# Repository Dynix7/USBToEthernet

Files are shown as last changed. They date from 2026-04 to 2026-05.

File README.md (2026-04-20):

# USBToEthernet
This is a design for USB to Ethernet Adapter that (obviously) allows you to use ethernet through a USB port.

# Why I Made It
I made this PCB because I was getting into setting up some sort of homeserver using my old laptop. However, my laptop doesn't have an ethernet port and while I could use WIFI, it wouldn't be optimal for network speed.

# Picture
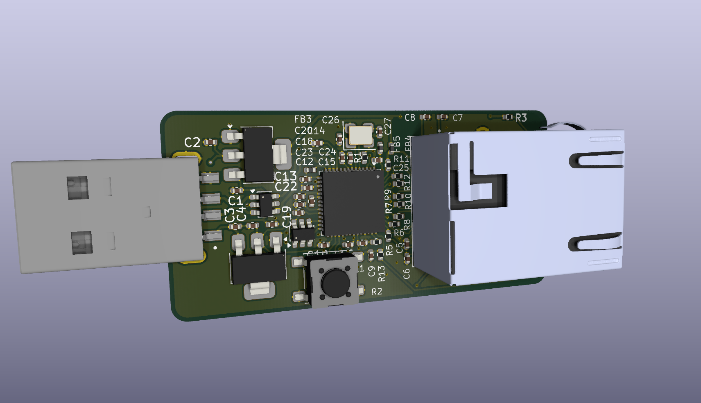
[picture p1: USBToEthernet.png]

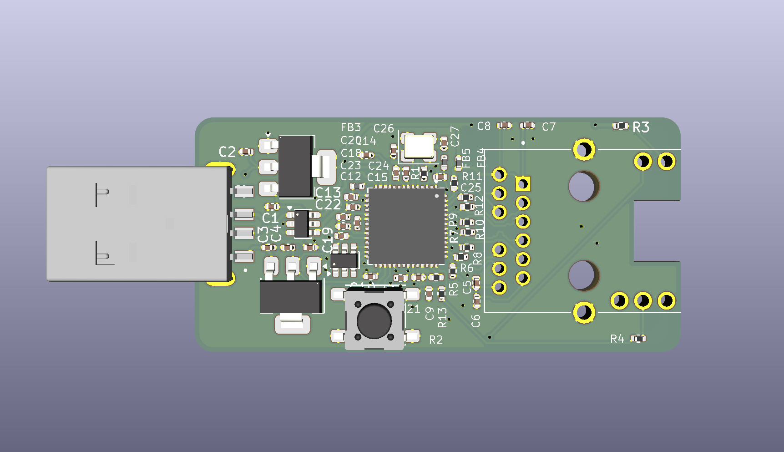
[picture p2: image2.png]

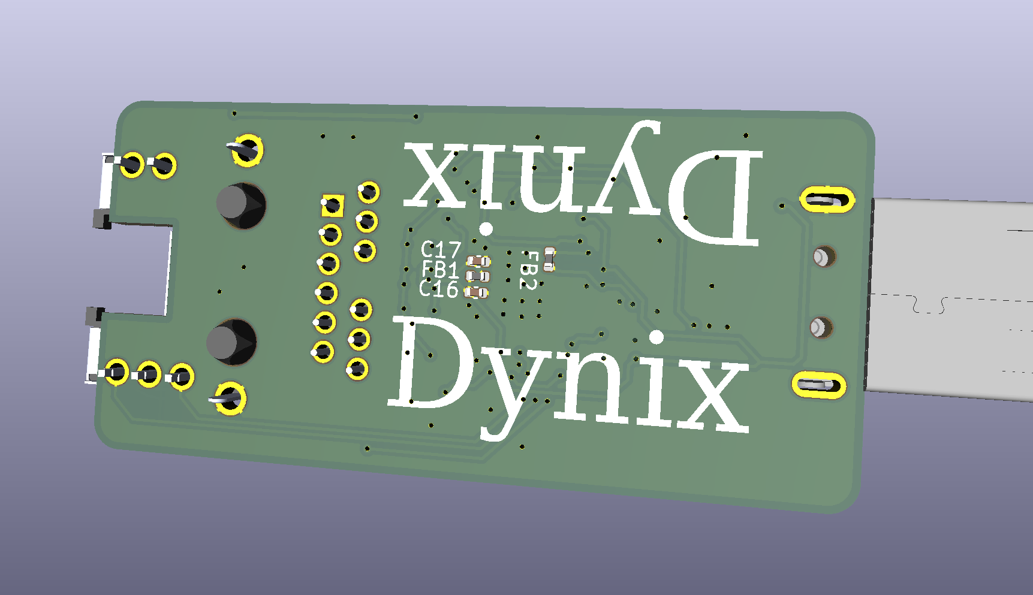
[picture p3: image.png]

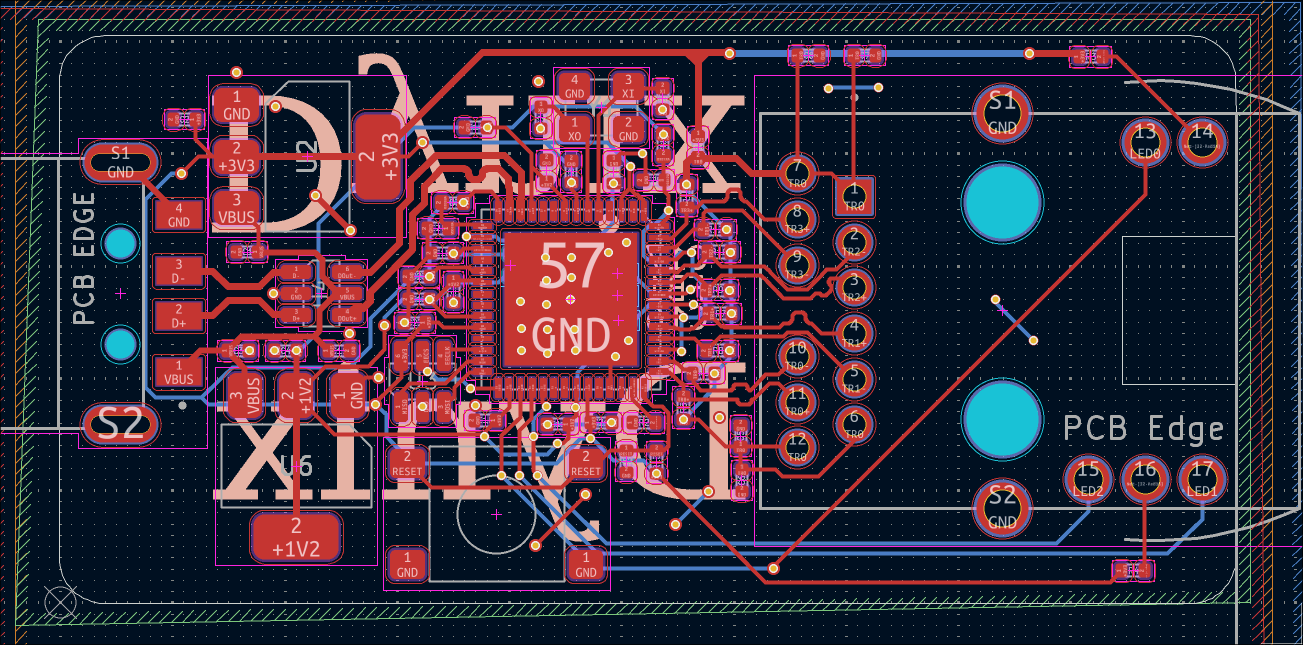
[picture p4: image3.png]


# BOM

|Name |Purpose |Quantity|Total Cost (USD)|Link |Distributor|
|---|---|---|---|---|---|
|10k Resistor |Resistor | |0.06 |https://www.lcsc.com/product-detail/C2906861.html|LCSC |
|8.06k Resistor |Resistor | |0.01 |https://www.lcsc.com/product-detail/C2960789.html|LCSC |
|12k Resistor |Resistor | |0.06 |https://www.lcsc.com/product-detail/C2909316.html|LCSC |
|1k Resistor |Resistor | |0.06 |https://www.lcsc.com/product-detail/C2906864.html|LCSC |
|49.9 Capcitor |Capacitor | |0.06 |https://www.lcsc.com/product-detail/C2933103.html|LCSC |
|24pF Capacitor |Capacitor | |0.12 |https://www.lcsc.com/product-detail/C281755.html |LCSC |
|100nF Capacitor |Decoupling Capacitor | |0.10 |https://www.lcsc.com/product-detail/C60474.html  |LCSC |
|10uF Capacitor |Capacitor | |0.18 |https://www.lcsc.com/product-detail/C14445.html  |LCSC |
|1uF Capacitor |Capacitor | |0.23 |https://www.lcsc.com/product-detail/C14445.html  |LCSC |
|22nF Capacitor |Capacitor | |0.20 |https://www.lcsc.com/product-detail/C1532.html |LCSC |
|120 Ohm Ferrite Bead |Power Filtering |5 |0.90 |https://www.digikey.com/short/c9nm3n45 |Digikey |
|USBLC6-2SC6 |Power Protection |1 |0.36 |https://www.digikey.com/short/m59b7dzr |Digikey |
|NCP1117 Voltage Regulator |Voltage Regulator |1 |0.38 |https://www.digikey.com/short/pvbpmpzr |Digikey |
|USB Plug |For Plugging Into Computer |1 |1.35 |https://www.digikey.com/short/75mfb4tp |Digikey |
|PTS645S Push Button |Reset Button |1 |0.36 |https://www.digikey.com/short/q00wnt84 |Digikey |
|L836-1J1T-43 Ehternet Jack|Ethernet Jack |1 |6.53 |https://www.digikey.com/short/7bz57dt5 |Digikey |
|AMS117 1.2V |Voltage Regulator for LAN7500 |1 |0.10 |https://www.digikey.com/short/jqn99nv8 |Digikey |
|93LC56AT-I/OT |Storage |1 |0.32 |https://www.digikey.com/short/z01d9wp0 |Digikey |
|TSX-3225 25Mhz Crystal |Crystal Oscillator for LAN7500|1 |0.38 |https://www.digikey.com/short/hw0jtcmv |Digikey |
|LAN7500-ABZJ |USB to Ethernet Chip |1 |7.00 |https://www.digikey.com/short/8pjfdmbz |Digikey |
|Stencil |Stencil for Manually Assembly |1 |7.11 | |JLCPCB |
|PCB |PCB for Build |5 |5.20 | |JLCPCB |

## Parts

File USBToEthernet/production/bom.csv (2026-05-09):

Designator | Footprint | Quantity | Value | LCSC Part #
C1, C12, C15_2, C15, C17, C18, C2, C20, C21, C3, C4, C5, C8 | 0402 | 13 | 1uF
C10, C11, C14, C16 | 0402 | 4 | 10uF
C13, C6 | 0402 | 2 | 100nF
C19, C22, C23, C24 | 0402 | 4 | 0.022uF
C7, C9 | 0402 | 2 | 24pF
FB1, FB2, FB3, FB4, FB5 | 0402 | 5 | 120@100
J1 | MOLEX_0480372200 | 1 | 0480372200
J2 | BEL_L836-1J1T-43 | 1 | L836-1J1T-43
R1 | 0402 | 1 | 12k
R10, R11 | 0402 | 2 | 1k
R12, R13, R4, R5, R6, R7, R8, R9 | 0402 | 8 | 49.9
R2 | 0402 | 1 | 8.06k
R3 | 0402 | 1 | 10k
SW1 | SW_SPST_PTS645Sx43SMTR92 | 1 | SW_Push
U1 | SOT-23-6 | 1 | 93LCxxAxxOT
U2 | QFN-56-1EP_8x8mm_P0.5mm_EP5.9x5.9mm | 1 | LAN7500-ABJZ
U3 | SOT-23-6 | 1 | USBLC6-2SC6
U4 | SOT-223-3_TabPin2 | 1 | NCP1117-3.3_SOT223
U5 | SOT-223-3_TabPin2 | 1 | AMS1117-1.2
Y1 | Crystal_SMD_SeikoEpson_FA238V-4Pin_3.2x2.5mm | 1 | 25Mhz

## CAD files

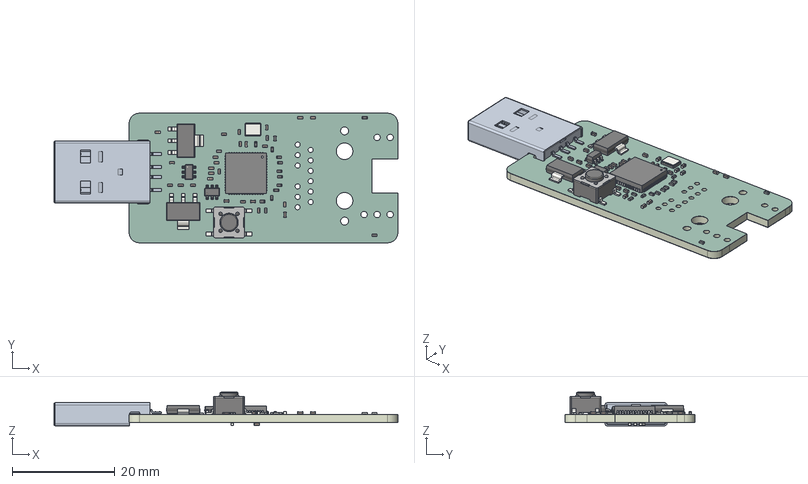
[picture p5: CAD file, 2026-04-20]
pcb.step
67.1 x 25.3 x 6.55 mm
L_0402_1005Metric x 5
R_0402_1005Metric x 13
SOT-23-6 x 2
C_0402_1005Metric x 27
SOT-223 x 2
QFN56_8X8MC_MCH
SW_SPST_PTS645Sx43SMTR92
Crystal_SMD_SeikoEpson_FA238V-4Pin_3.2x2.5mm
USBToEthernet_soldermask x 2
USBToEthernet_PCB

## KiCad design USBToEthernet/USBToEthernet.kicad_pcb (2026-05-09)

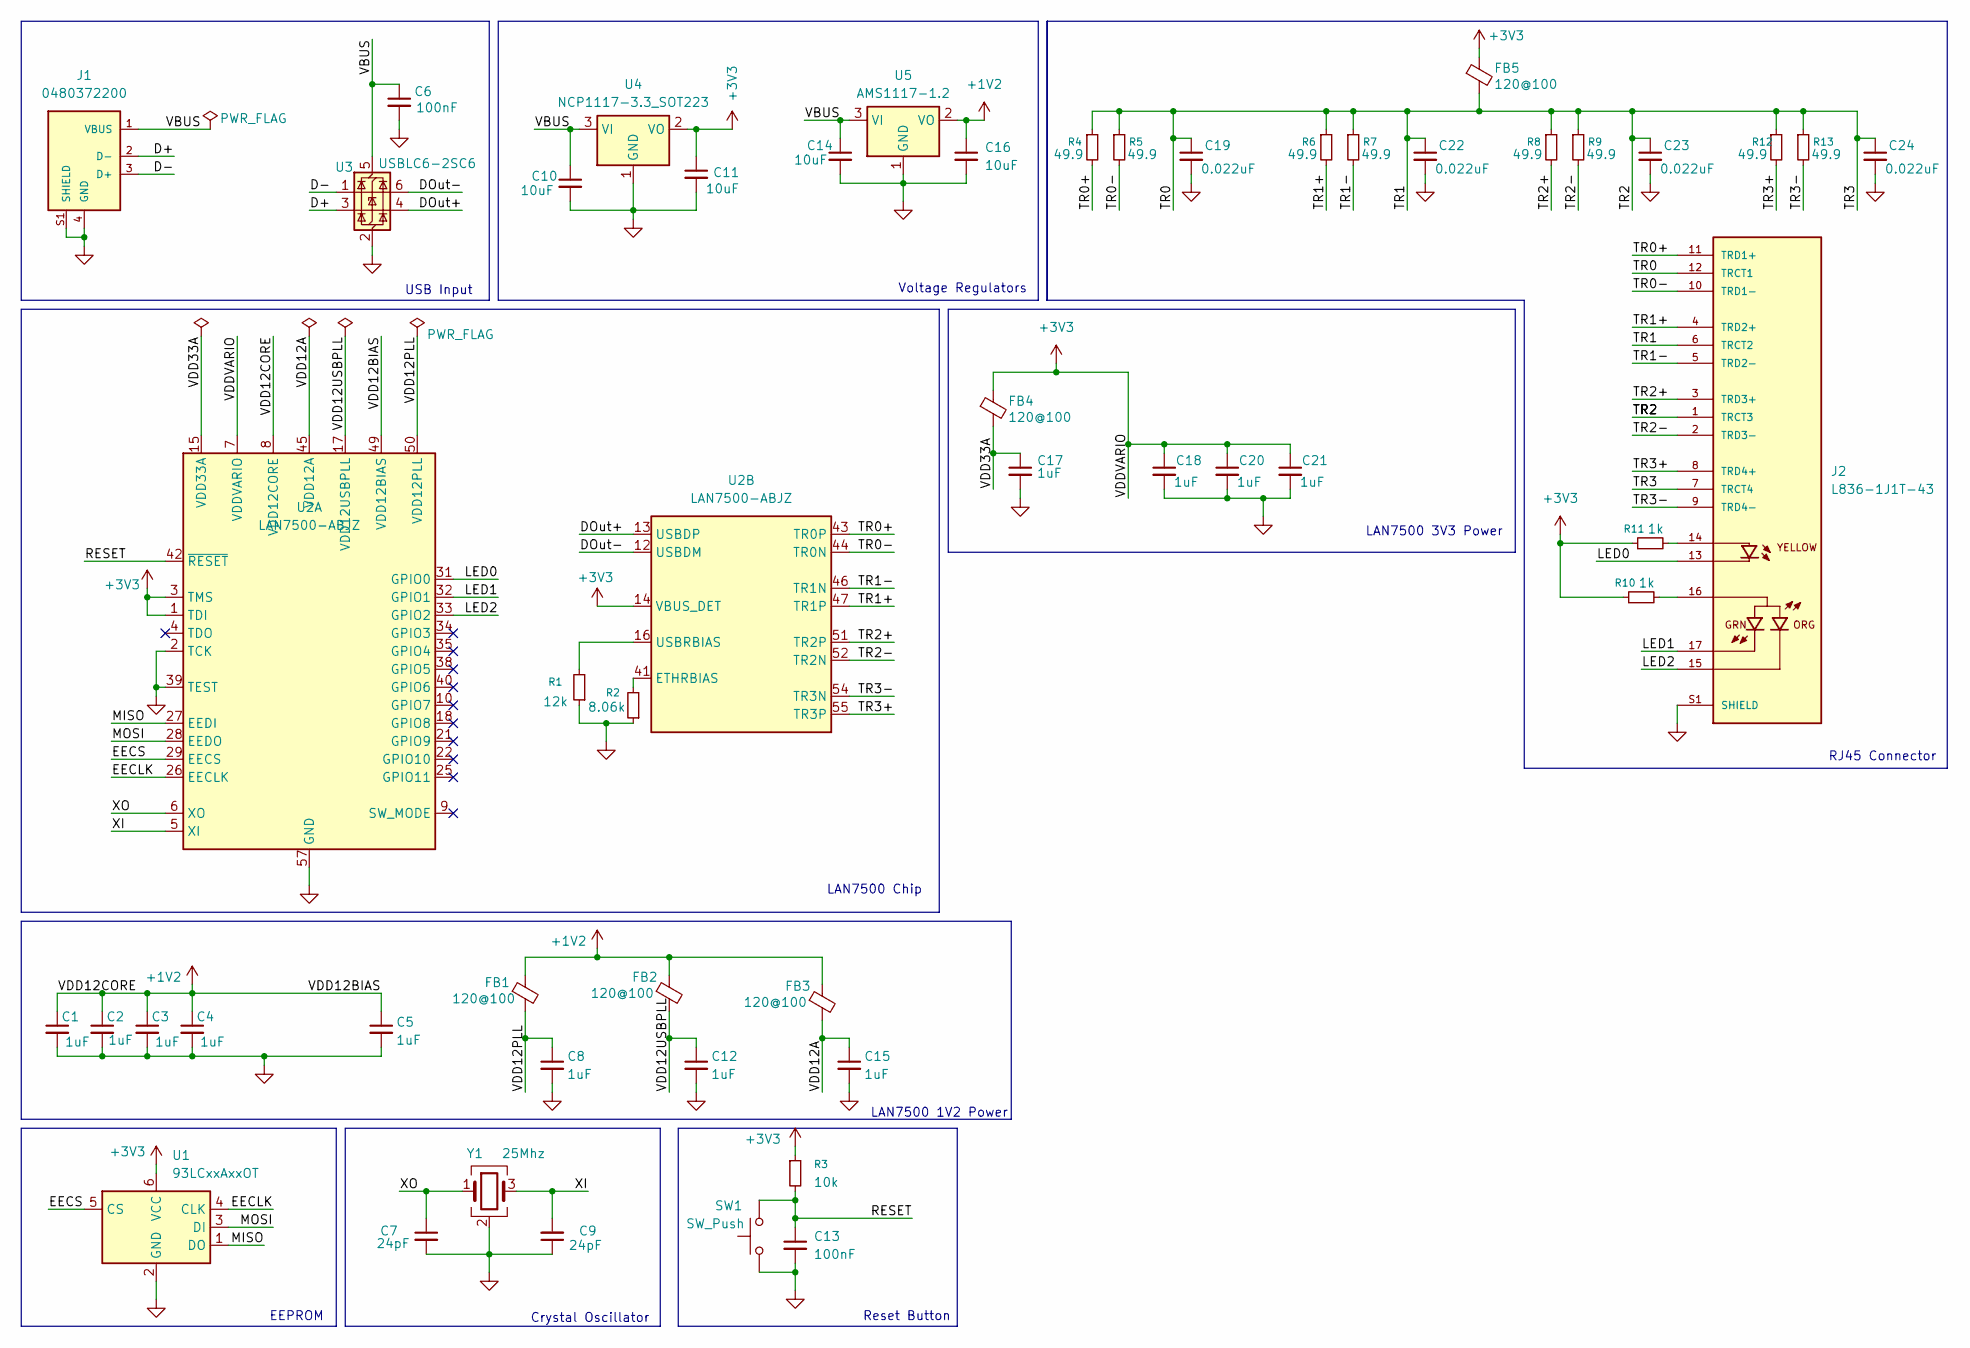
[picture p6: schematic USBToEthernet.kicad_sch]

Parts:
C1, C2, C3, C4, C12, C15, C17, C18, C20, C21: 1uF; C_0402_1005Metric
C5, C8: 1uF; C_0402_1005Metric_Pad0.74x0.62mm_HandSolder
C6, C13: 100nF; C_0402_1005Metric
C7, C9: 24pF; C_0402_1005Metric
C10, C11, C14, C16: 10uF; C_0402_1005Metric
C19, C22, C23, C24: 0.022uF; C_0402_1005Metric
FB1, FB2: 120@100; L_0402_1005Metric_Pad0.77x0.64mm_HandSolder
FB3, FB4, FB5: 120@100; L_0402_1005Metric
J1: 0480372200; MOLEX_0480372200
J2: L836-1J1T-43; BEL_L836-1J1T-43; PARTREV B; DigiKey_Part_Number 5923-L836-1J1T-43-ND
R1: 12k; R_0402_1005Metric_Pad0.72x0.64mm_HandSolder
R2: 8.06k; R_0402_1005Metric
R3: 10k; R_0402_1005Metric
R4, R5, R6, R7, R8, R9, R12, R13: 49.9; R_0402_1005Metric
R10, R11: 1k; R_0402_1005Metric
SW1: SW_Push; SW_SPST_PTS645Sx43SMTR92
U1: 93LCxxAxxOT; SOT-23-6
U2: LAN7500-ABJZ; QFN-56-1EP_8x8mm_P0.5mm_EP5.9x5.9mm
U3: USBLC6-2SC6; SOT-23-6
U4: NCP1117-3.3_SOT223; SOT-223-3_TabPin2
U5: AMS1117-1.2; SOT-223-3_TabPin2
Y1: 25Mhz; Crystal_SMD_SeikoEpson_FA238V-4Pin_3.2x2.5mm

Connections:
+1V2: C1.1, C2.1, C3.1, C4.1, C5.1, C16.1, FB1.1, FB2.1, FB3.1, U2.8 (VDD12CORE), U2.11 (VDD12CORE), U2.20 (VDD12CORE), U2.23 (VDD12CORE), U2.30 (VDD12CORE), U2.36 (VDD12CORE), U2.49 (VDD12BIAS), U5.2 (VO); also elsewhere on the board
+3V3: C11.1, C18.1, C20.1, C21.1, FB4.1, FB5.1, R3.1, R10.1, R11.1, U1.6 (VCC), U2.1 (TDI), U2.3 (TMS), U2.7 (VDDVARIO), U2.14 (VBUS_DET), U2.19 (VDDVARIO), U2.24 (VDDVARIO), U2.37 (VDDVARIO), U4.2 (VO)
/D+: J1.2 (D-), U3.3 (I/O2)
/D-: J1.3 (D+), U3.1 (I/O1)
/DOut+: U2.13 (USBDP), U3.4 (I/O2)
/DOut-: U2.12 (USBDM), U3.6 (I/O1)
/EECLK: U1.4 (CLK), U2.26 (EECLK)
/EECS: U1.5 (CS), U2.29 (EECS)
/LED0: J2.13, U2.31 (GPIO0)
/LED1: J2.17, U2.32 (GPIO1)
/LED2: J2.15, U2.33 (GPIO2)
/MISO: U1.1 (DO), U2.27 (EEDI)
/MOSI: U1.3 (DI), U2.28 (EEDO)
/RESET: C13.1, R3.2, SW1.2, U2.42 (~RESET)
/TR0: C19.1, C22.1, C23.1, C24.1, FB5.2, J2.1 (TRCT3), J2.6 (TRCT2), J2.7 (TRCT4), J2.12 (TRCT1), R4.1, R5.1, R6.1, R7.1, R8.1, R9.1, R12.1, R13.1
/TR0+: J2.11 (TRD1+), R4.2, U2.43 (TR0P)
/TR0-: J2.10 (TRD1-), R5.2, U2.44 (TR0N)
/TR1+: J2.4 (TRD2+), R6.2, U2.47 (TR1P)
/TR1-: J2.5 (TRD2-), R7.2, U2.46 (TR1N)
/TR2+: J2.3 (TRD3+), R8.2, U2.51 (TR2P)
/TR2-: J2.2 (TRD3-), R9.2, U2.52 (TR2N)
/TR3+: J2.8 (TRD4+), R12.2, U2.55 (TR3P)
/TR3-: J2.9 (TRD4-), R13.2, U2.54 (TR3N)
/VBUS: C6.1, C10.1, C14.1, J1.1 (VBUS), U3.5 (VBUS), U4.3 (VI), U5.3 (VI)
/VDD12A: C15.1, FB3.2, U2.45 (VDD12A), U2.48 (VDD12A), U2.53 (VDD12A), U2.56 (VDD12A)
/VDD12PLL: C8.1, FB1.2, U2.50 (VDD12PLL)
/VDD12USBPLL: C12.1, FB2.2, U2.17 (VDD12USBPLL)
/VDD33A: C17.1, FB4.2, U2.15 (VDD33A)
/XI: C9.2, U2.5 (XI), Y1.3
/XO: C7.1, U2.6 (XO), Y1.1
GND: C1.2, C2.2, C3.2, C4.2, C5.2, C6.2, C7.2, C8.2, C9.1, C10.2, C11.2, C12.2, C13.2, C14.2, C15.2, C16.2, C17.2, C18.2, C19.2, C20.2, C21.2, C22.2, C23.2, C24.2, J1.4 (GND), J1.S1 (SHIELD), J2.S1 (SHIELD), J2.S2 (SHIELD), R1.1, R2.1, SW1.1, U1.2 (GND), U2.2 (TCK), U2.39 (TEST), U2.57 (GND), U3.2 (GND), U4.1 (GND), U5.1 (GND), Y1.2 (G), Y1.4 (G); also elsewhere on the board
unnamed: J2.14, R11.2
unnamed: J2.16, R10.2
unnamed: R2.2, U2.41 (ETHRBIAS)
unnamed: R1.2, U2.16 (USBRBIAS)

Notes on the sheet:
LAN7500 3V3 Power
USB Input
EEPROM
LAN7500 1V2 Power
Crystal Oscillator
Reset Button
LAN7500 Chip
RJ45 Connector
Voltage Regulators

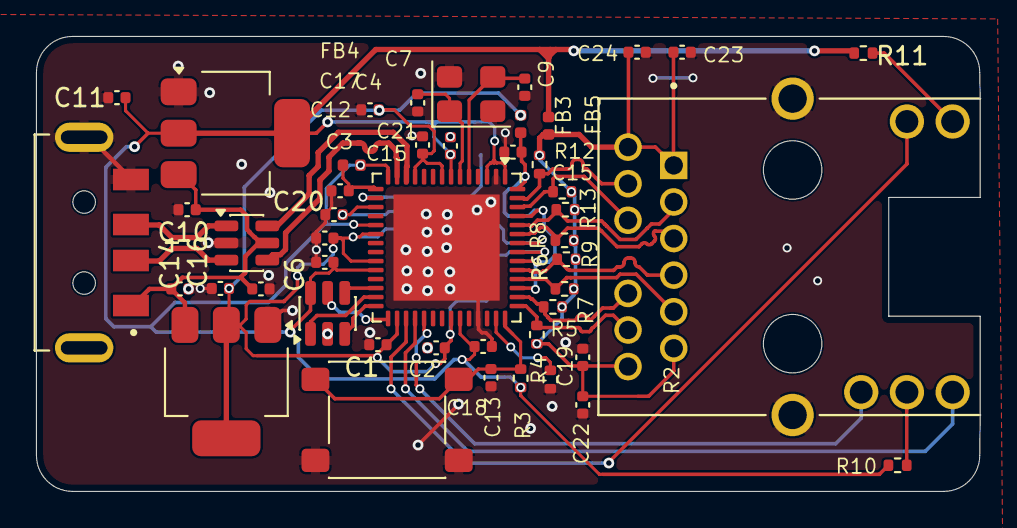
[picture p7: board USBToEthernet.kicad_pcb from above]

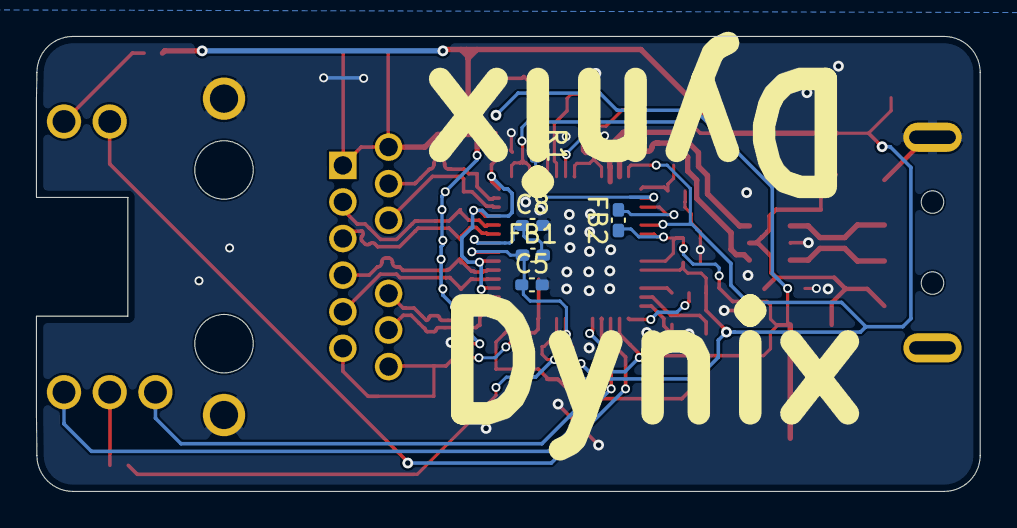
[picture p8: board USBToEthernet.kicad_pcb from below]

Board: 4 copper layers, 52.4 x 25.3 mm, 52 parts (5 on the bottom side), 35 nets.

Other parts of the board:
C15#2: 1uF; C_0402_1005Metric

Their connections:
+1V2: C15#2.1; also elsewhere on the board
GND: C15#2.2; also elsewhere on the board

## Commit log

2026-02-18 Added parts
    [USBToEthernet.kicad_pcb, USBToEthernet.kicad_sch]
2026-02-18 Added library for RJ45
    [RJMG1S8008101BR.step, USBToEthernet.kicad_sch]
2026-02-19 Finished wiring RJ45 and most of LAN7500
    [L836-1J1T-43.step, RJMG1S8008101BR.step, USBToEthernet.kicad_sch]
2026-02-19 Finished schematic
    [USBToEthernet.kicad_pcb, USBToEthernet.kicad_sch]
2026-02-20 misc. changes
    [USBToEthernet.kicad_sch]
2026-02-20 Add external load capacitors for oscillator
    [USBToEthernet.kicad_sch]
2026-02-20 Add footprints for the oscillator load capacitors
    [USBToEthernet.kicad_pcb, USBToEthernet.kicad_sch]
2026-02-20 capacitor footprint
2026-02-20 Most placements I think done
    [USBToEthernet.kicad_pcb, USBToEthernet.kicad_sch]
2026-02-21 Fried ahh PCB layout and routing
    [USBToEthernet.kicad_pcb, USBToEthernet.kicad_sch]
2026-02-21 Will redo layout
    [USBToEthernet.kicad_sch]
2026-02-22 Revamped the PCB
    [USBToEthernet-B_Cu.gbr, USBToEthernet-B_Mask.gbr, USBToEthernet-B_Paste.gbr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]
2026-02-24 Change Via hole size
    [BOM.csv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]
2026-03-07 Reroute again
    [USBToEthernet.kicad_pcb, USBToEthernet.kicad_sch, USBToEthernet.stl]
2026-03-07 Reroute and other changes
    [USBToEthernet-B_Cu.gbr, USBToEthernet-B_Mask.gbr, USBToEthernet-B_Paste.gbr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]
2026-04-02 update repo fr
    [USBToEthernet.kicad_pcb, bom.csv, designators.csv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]
2026-04-19 update ibom and production
    [USBToEthernet-B_Cu.gbr, USBToEthernet-B_Mask.gbr, USBToEthernet-B_Paste.gbr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]
2026-05-09 Added more space between capacitors
    [USBToEthernet.kicad_pcb, USBToEthernet.kicad_sch, bom.csv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]
